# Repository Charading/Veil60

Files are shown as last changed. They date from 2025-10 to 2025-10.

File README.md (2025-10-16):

# The Veil 60% Keyboard
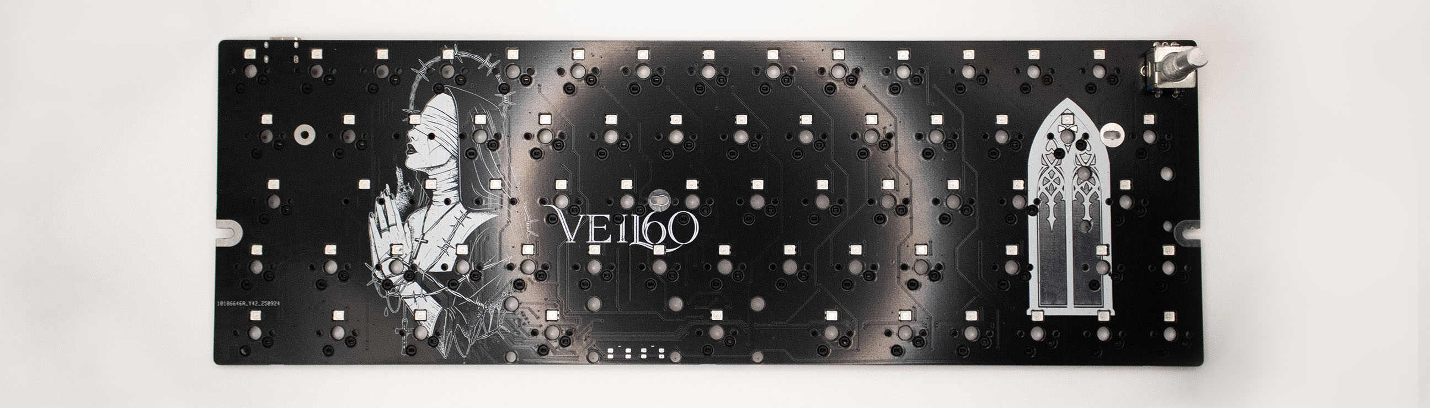
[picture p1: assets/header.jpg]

## Features and Information
- 66 key 60% layout, compatible with 3rd party cases.
- QMK + VIA
- Split space (2.75U + 2.25U + 1.25U)
- WASD are Hall effect sensors with SOCD.
- Custom VIA keycodes for printing ADC values to QMK Toolbox HID Console for calibration
- Fully remappable encoder knob.
- Arrow key cluster
- ISO backslash
- SignalRGB supported
- North-facing RGB
- 12 Underglow LEDS

### [KLE Layout](https://www.keyboard-layout-editor.com/#/gists/70c935bfc0dd9d3efd5b4094877e21a2)
<p align="center">
PCB Front
</p>

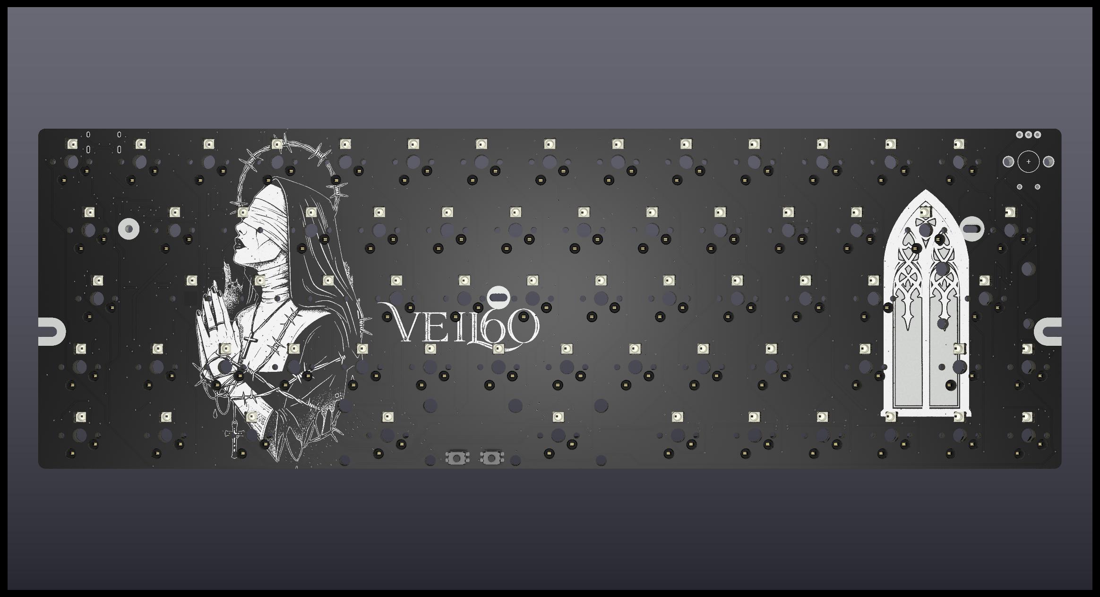
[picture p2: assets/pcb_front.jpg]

<p align="center">
PCB Back
</p>

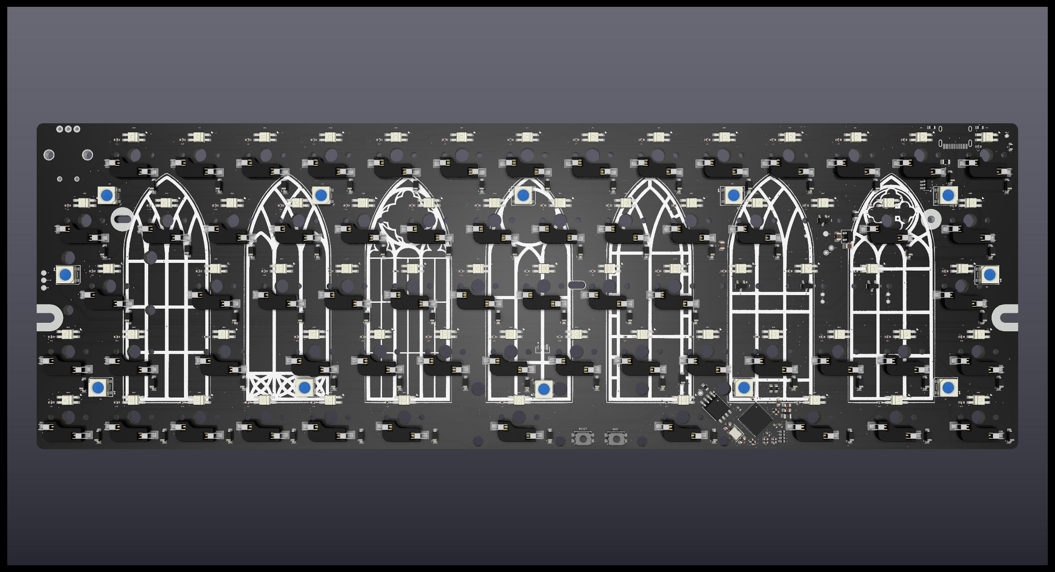
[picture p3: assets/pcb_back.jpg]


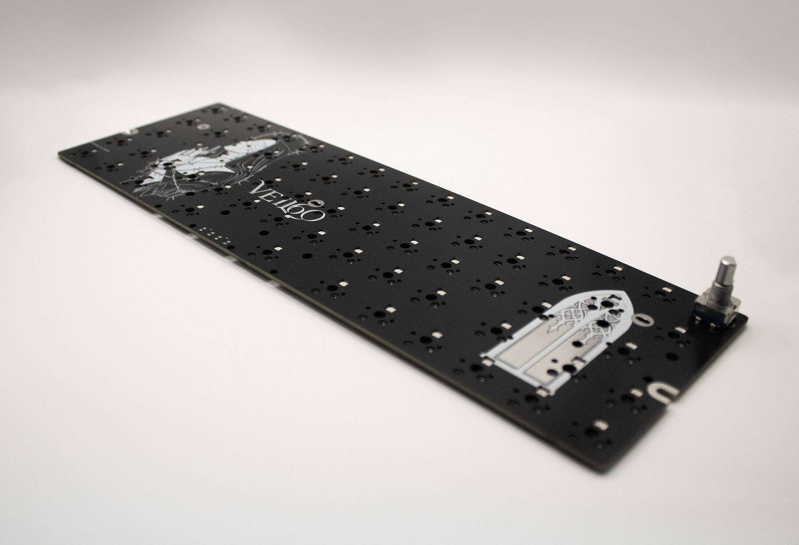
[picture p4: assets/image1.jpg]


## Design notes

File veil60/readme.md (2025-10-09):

# veil60

veil60

*A short description of the keyboard/project*

* Keyboard Maintainer: [Charading](https://github.com/Charading)
* Hardware Supported: *The PCBs, controllers supported*
* Hardware Availability: *Links to where you can find this hardware*

Make example for this keyboard (after setting up your build environment):

    make veil60:default

Flashing example for this keyboard:

    make veil60:default:flash

See the [build environment setup](https://docs.qmk.fm/#/getting_started_build_tools) and the [make instructions](https://docs.qmk.fm/#/getting_started_make_guide) for more information. Brand new to QMK? Start with our [Complete Newbs Guide](https://docs.qmk.fm/#/newbs).

## Bootloader

Enter the bootloader in 3 ways:

* **Bootmagic reset**: Hold down the key at (0,0) in the matrix (usually the top left key or Escape) and plug in the keyboard
* **Physical reset button**: Briefly press the button on the back of the PCB - some may have pads you must short instead
* **Keycode in layout**: Press the key mapped to `QK_BOOT` if it is available

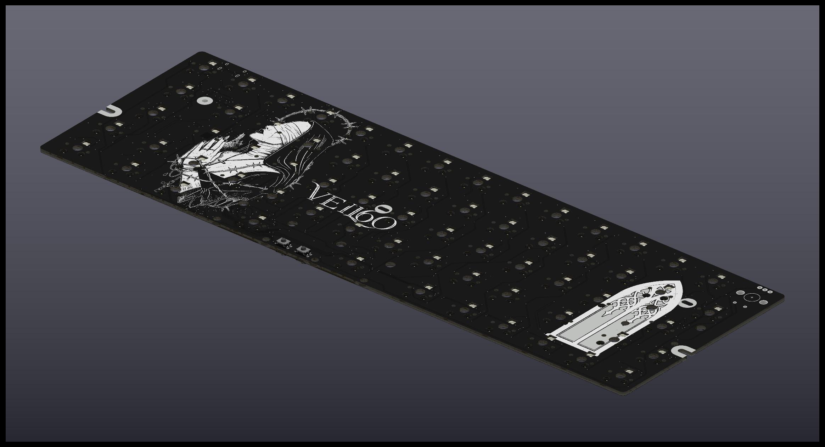
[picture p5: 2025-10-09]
assets/pcb_front_ortho.jpg

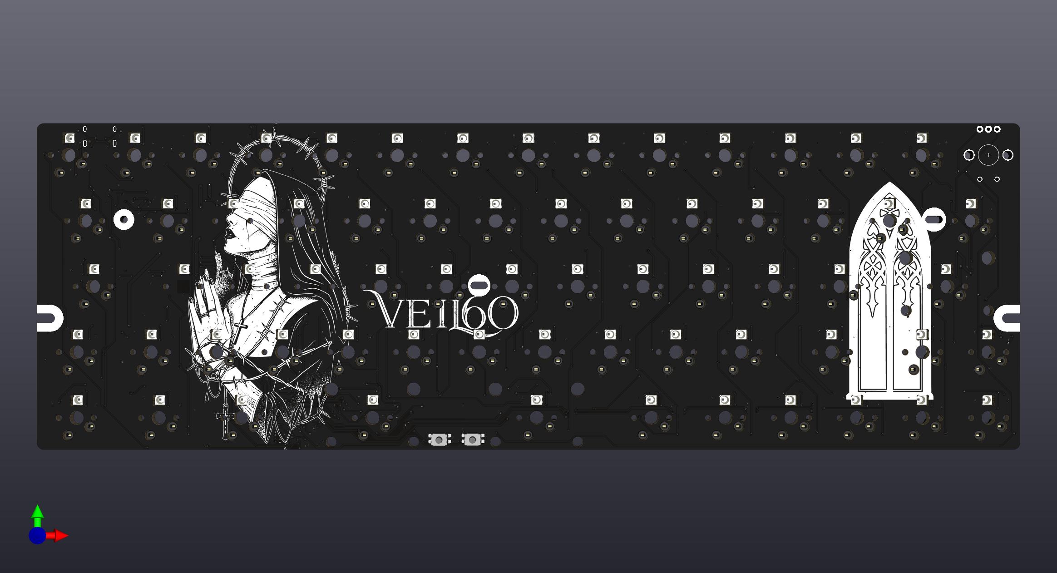
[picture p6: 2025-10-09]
assets/pcb_front_default.jpg

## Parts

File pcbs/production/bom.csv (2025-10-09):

Designator | Footprint | Quantity | Value | LCSC Part #
AC1, AC2, AC3, AC4, C1, C14, C16, C17, C2, C3, C4, C5, C6 | C_0402 | 13 | 0.1uF
BOOT_2, BOOT | SW_SPST_EVQP2_MiddlePushTravel_H2.5mm | 2 | BOOT
C1_2, C2_3, C2_2, C3_2 | TestPoint_Pad_D1.0mm | 4 | 0.1uF
C10 | 0603 | 1 | 0.1uF
C11, C9 | 0603 | 2 | 10uF
C12, C13 | 0603 | 2 | 30p
C15 | C_0402 | 1 | 1u
C18 | 0805 | 1 | 10u
C7, C8 | 0805 | 2 | 4.7uF
D1, D10, D11, D12, D13, D14, D15, D16, D17, D18, D19, D2, D20, D21, D22, D23, D24, D25, D26, D27, D28, D29, D3, D30, D31, D32, D33, D34, D35, D36, D37, D38, D39, D4, D40, D41, D42, D43, D44, D45, D46, D47, D48, D49, D5, D50, D51, D52, D53, D54, D55, D56, D57, D58, D59, D6, D60, D61, D62, D7, D8, D9 | D_SOD-123_Mars | 62 | 1N4148W
ENC1 | RotaryEncoder_MX_EC11_CircularMountingHoles | 1 | RotaryEncoder_Switch_MP
F1 | 0805 | 1 | Polyfuse_Small
FB1 | Ferrite_0805 | 1 | 600R
J1 | USB_C_Receptacle_HRO_TYPE-C-31-M-12 (16P) | 1 | USB_C_Receptacle
L1 | 0805 | 1 | 10uH
LC1, LC10, LC11, LC12, LC13, LC14, LC15, LC16, LC17, LC18, LC19, LC2, LC20, LC21, LC22, LC23, LC24, LC25, LC26, LC27, LC28, LC29, LC3, LC30, LC31, LC32, LC33, LC34, LC35, LC36, LC37, LC38, LC39, LC4, LC40, LC41, LC42, LC43, LC44, LC45, LC46, LC47, LC48, LC49, LC5, LC50, LC51, LC52, LC53, LC54, LC55, LC56, LC57, LC58, LC59, LC6, LC60, LC61, LC62, LC63, LC64, LC65, LC66, LC7, LC8, LC9 | 0402 | 66 | 100n
LED1, LED10, LED11, LED12, LED13, LED14, LED15, LED16, LED17, LED18, LED19, LED2, LED20, LED21, LED22, LED23, LED24, LED25, LED26, LED27, LED28, LED29, LED3, LED30, LED31, LED32, LED33, LED34, LED35, LED36, LED37, LED38, LED39, LED4, LED40, LED41, LED42, LED43, LED44, LED45, LED46, LED47, LED48, LED49, LED5, LED50, LED51, LED52, LED53, LED54, LED55, LED56, LED57, LED58, LED59, LED6, LED60, LED61, LED62, LED63, LED64, LED65, LED66, LED7, LED8, LED9 | LED_6028R | 66 | SK6812MINI-E
MX1 | MX-Hotswap-1U | 1 | Esc
MX10 | MX-Hotswap-1U | 1 | 9
MX11 | MX-Hotswap-1U | 1 | 10
MX12 | MX-Hotswap-1U | 1 | -
MX13 | MX-Hotswap-1U | 1 | =
MX14 | MX-Hotswap-1U | 1 | Back
MX15 | MX-Hotswap-1.5U | 1 | Tab
MX16 | MX-Hotswap-1U | 1 | Q
MX17 | SW_MX_HE_90deg_1u | 1 | W
MX18 | MX-Hotswap-1U | 1 | E
MX19 | MX-Hotswap-1U | 1 | R
MX2 | MX-Hotswap-1U | 1 | 1
MX20 | MX-Hotswap-1U | 1 | T
MX21 | MX-Hotswap-1U | 1 | Y
MX22 | MX-Hotswap-1U | 1 | U
MX23 | MX-Hotswap-1U | 1 | I
MX24 | MX-Hotswap-1U | 1 | O
MX25 | MX-Hotswap-1U | 1 | P
MX26 | MX-Hotswap-1U | 1 | [
MX27 | MX-Hotswap-1U | 1 | ]
MX28 | MX-Hotswap-1.5U | 1 | #
MX29 | MX-Hotswap-1.75U | 1 | Caps
MX3 | MX-Hotswap-1U | 1 | 2
MX30 | SW_MX_HE_90deg_1u | 1 | A
MX31 | SW_MX_HE_90deg_1u | 1 | S
MX32 | SW_MX_HE_90deg_1u | 1 | D
MX33 | MX-Hotswap-1U | 1 | F
MX34 | MX-Hotswap-1U | 1 | G
MX35 | MX-Hotswap-1U | 1 | H
MX36 | MX-Hotswap-1U | 1 | J
MX37 | MX-Hotswap-1U | 1 | K
MX38 | MX-Hotswap-1U | 1 | L
MX39 | MX-Hotswap-1U | 1 | ;:
MX4 | MX-Hotswap-1U | 1 | 3
MX40 | MX-Hotswap-1U | 1 | '@
MX41 | MX-Hotswap-2.25U | 1 | Enter
MX42 | MX-Hotswap-1.25U | 1 | L_Shift
MX43 | MX-Hotswap-1U | 1 | \
MX44 | MX-Hotswap-1U | 1 | Z
MX45 | MX-Hotswap-1U | 1 | X
MX46 | MX-Hotswap-1U | 1 | C
MX47 | MX-Hotswap-1U | 1 | V
MX48 | MX-Hotswap-1U | 1 | B
MX49 | MX-Hotswap-1U | 1 | N
MX5 | MX-Hotswap-1U | 1 | 4
MX50 | MX-Hotswap-1U | 1 | M
MX51 | MX-Hotswap-1U | 1 | ,<
MX52 | MX-Hotswap-1U | 1 | .>
MX53 | MX-Hotswap-1.75U | 1 | R_Shift
MX54 | MX-Hotswap-1U | 1 | Up
MX55 | MX-Hotswap-1U | 1 | /?
MX56 | MX-Hotswap-1.25U | 1 | L_Ctrl
MX57 | MX-Hotswap-1.25U | 1 | Win
MX58 | MX-Hotswap-1.25U | 1 | L_Alt
MX59 | MX-Hotswap-2.75U | 1 | Space1
MX6 | MX-Hotswap-1U | 1 | 5
MX60 | MX-Hotswap-2.25U | 1 | Space2
MX61 | MX-Hotswap-1.25U | 1 | Space3
MX62 | MX-Hotswap-1U | 1 | R_Alt
MX63 | MX-Hotswap-1U | 1 | Fn
MX64 | MX-Hotswap-1U | 1 | Left
MX65 | MX-Hotswap-1U | 1 | Down
MX66 | MX-Hotswap-1U | 1 | Right
MX7 | MX-Hotswap-1U | 1 | 6
MX8 | MX-Hotswap-1U | 1 | 7
MX9 | MX-Hotswap-1U | 1 | 8
R1_2, R2_4, R2_3, R2_2 | TestPoint_Pad_D1.0mm | 4 | 5.1k
R1, R2 | R_0603 | 2 | 5.1k
R10, R7, R8, R9 | R_0402 | 4 | 1k
R3 | R_0603 | 1 | 10K
R4, R5 | R_0603 | 2 | 27R
R6 | R_0603 | 1 | 330
RESET_2, RESET | SW_SPST_EVQP2_MiddlePushTravel_H2.5mm | 2 | RESET
U1 | SOT-23-5 | 1 | AP2112K-3.3TRG1
U2 | SOT-23-6 | 1 | USBLC6-2SC6
U3 | SOIC-8_5.3x5.3mm_P1.27mm | 1 | W25Q128JVS
U4 | QFN-56-1EP_7x7mm_P0.4mm_EP3.2x3.2mm | 1 | RP2040
UG1 | LED_WS2812B-4020 | 1 | WS2812_4020
UL1, UL10, UL11, UL12, UL2, UL3, UL4, UL5, UL6, UL7, UL8, UL9 | LED_WS2812B_PLCC4_5.0x5.0mm_P3.2mm | 12 | WS2812B
Y1 | Crystal_SMD_3225-4Pin_3.2x2.5mm | 1 | 12MHz

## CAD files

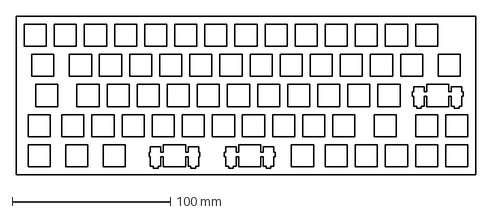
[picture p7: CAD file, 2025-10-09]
veil60/veil60_plate.dxf
290.7 x 100.2 mm

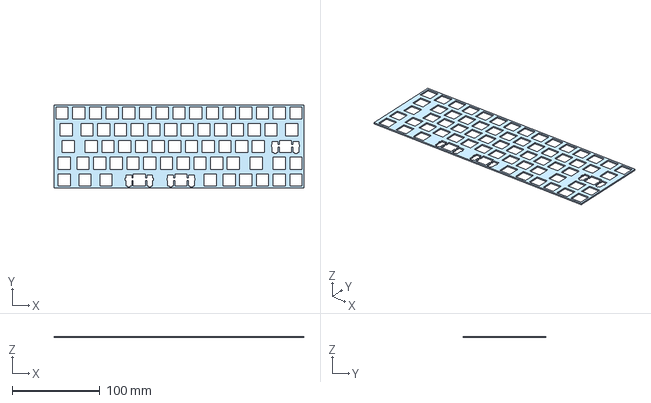
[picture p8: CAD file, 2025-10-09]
veil60_plate.step
285.0 x 94.6 x 1.50 mm

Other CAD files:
veil60_plate_split.step

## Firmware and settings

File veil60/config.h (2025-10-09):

#pragma once

// Console for debugging (enabled via keyboard.json)


#define ENCODER_BUTTON_PIN GP14


// ADC configuration for DRV5055A4 hall effect sensors
#define ADC_BUFFER_DEPTH 4
#define ADC_SAMPLING_RATE 10000


// SOCD configuration
#define SOCD_TIMEOUT 50 // ms timeout for SOCD cleaning

// Custom matrix scanning interval
#define MATRIX_SCAN_RATE 1000 // 1kHz scan rate for hall effect sensors

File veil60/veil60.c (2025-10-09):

#include "veil60.h"
#include "socd.h"
#include "analog.h"
#include "timer.h"
#include "print.h"
#include "config.h"

// Hall sensor states
static hall_sensor_t hall_sensors[4] = {0};
static uint32_t last_adc_print = 0;

// Hall effect sensor threshold (single threshold, no hysteresis)
// DRV5055A4: typical mid-scale ~2048 for 12-bit; values here are raw ADC units
// Actuation when ADC > HALL_THRESHOLD, release when ADC <= HALL_THRESHOLD
#define HALL_THRESHOLD 545

#include "bootloader.h"
// Note: BOOT keycode is defined in the keymap as BOOT_KEY (SAFE_RANGE). Do not redefine here.
// Bootloader helper is available via bootloader.h
// ...existing code...


// Hall sensor scanning (runs alongside normal matrix)
void hall_sensor_scan(void) {
    // Scan every cycle for gaming (no delay)
    hall_sensors_task();
    
    // Print ADC values every 100ms for calibration
    if (timer_elapsed32(last_adc_print) > 100) {
        print_adc_values();
        last_adc_print = timer_read32();
    }
}

void hall_sensors_init(void) {
    // Initialize ADC pins
    analogReadPin(KEY_W);
    analogReadPin(KEY_A);
    analogReadPin(KEY_S);
    analogReadPin(KEY_D);
    
    // Initialize SOCD
    socd_init();
    // Init encoder switch if defined
#ifdef ENCODER_BUTTON_PIN
    setPinInputHigh(ENCODER_BUTTON_PIN); // enable pull-up
#endif
    // Initialize debounce state for hall sensors
    for (int i = 0; i < 4; ++i) {
        hall_sensors[i].last_debounce = timer_read32();
        hall_sensors[i].raw_pressed = false;
        hall_sensors[i].previous_state = false;
        hall_sensors[i].sent_state = false;
        hall_sensors[i].desired_state = false;
        hall_sensors[i].raw_value = 0;
    }
}

void hall_sensors_task(void) {
    // Read all hall sensors
    read_hall_sensor(ADC_W_CHANNEL, &hall_sensors[0]);
    read_hall_sensor(ADC_A_CHANNEL, &hall_sensors[1]);
    read_hall_sensor(ADC_S_CHANNEL, &hall_sensors[2]);
    read_hall_sensor(ADC_D_CHANNEL, &hall_sensors[3]);
    
    // Process key states with SOCD and direct keycode injection
    for (uint8_t i = 0; i < 4; ++i) {
        if (hall_sensors[i].is_pressed != hall_sensors[i].previous_state) {
            // Map sensor index to keycode
            uint16_t kc = KC_NO;
            switch (i) {
                case 0: kc = KC_W; break;
                case 1: kc = KC_A; break;
                case 2: kc = KC_S; break;
                case 3: kc = KC_D; break;
            }
            
            // Process through SOCD system with is_hall=true
            // This will automatically handle register_code/unregister_code calls
            socd_process_key(kc, hall_sensors[i].is_pressed, true);
            
            hall_sensors[i].sent_state = hall_sensors[i].is_pressed;
            hall_sensors[i].previous_state = hall_sensors[i].is_pressed;
        }
    }
}

bool read_hall_sensor(uint8_t channel, hall_sensor_t* sensor) {
    uint16_t adc_value;
    
    switch (channel) {
        case ADC_W_CHANNEL:
            adc_value = analogReadPin(KEY_W);
            break;
        case ADC_A_CHANNEL:
            adc_value = analogReadPin(KEY_A);
            break;
        case ADC_S_CHANNEL:
            adc_value = analogReadPin(KEY_S);
            break;
        case ADC_D_CHANNEL:
            adc_value = analogReadPin(KEY_D);
            break;
        default:
            return false;
    }
    
    sensor->raw_value = adc_value;
    // Simple debounce: detect raw pressed state and require it to be stable for 30ms
    bool currently_raw = (adc_value > HALL_THRESHOLD);
    if (currently_raw != sensor->raw_pressed) {
        // state changed, reset debounce timer
        sensor->last_debounce = timer_read32();
        sensor->raw_pressed = currently_raw;
    }
    // Only commit to is_pressed if stable for 30ms
    if (timer_elapsed32(sensor->last_debounce) >= 30) {
        sensor->is_pressed = sensor->raw_pressed;
    }
    
    return true;
}

void print_adc_values(void) {
    // Only print if enabled by keymap (ADC debug prints are allowed)
    if (adc_printing_enabled) {
        uprintf("ADC: W=%d A=%d S=%d D=%d | Pressed: W=%d A=%d S=%d D=%d\n",
                hall_sensors[0].raw_value,
                hall_sensors[1].raw_value,
                hall_sensors[2].raw_value,
                hall_sensors[3].raw_value,
                hall_sensors[0].is_pressed,
                hall_sensors[1].is_pressed,
                hall_sensors[2].is_pressed,
                hall_sensors[3].is_pressed);
    }
}

// QMK callback: Initialize keyboard
void keyboard_pre_init_kb(void) {
    hall_sensors_init();
    keyboard_pre_init_user();
}

// QMK callback: Called every matrix scan cycle
void matrix_scan_kb(void) {
    // Scan hall effect sensors (runs on top of normal matrix)
    hall_sensor_scan();
    
    // Run SOCD task
    socd_task();
    
    // Hall sensors now use direct keycode injection instead of matrix injection
    // No need to manipulate matrix[] directly or process physical inputs
    
    // Call user's matrix_scan callback
    matrix_scan_user();
}

// Trigger RP2040 bootloader safely from code or keymap
void veil60_bootloader(void) {
#if defined(RESET_USB_BOOT) || defined(usb_boot)
    // Prefer QMK helper if available
    reset_usb_boot(0, 0);
#elif defined(bootloader_jump)
    bootloader_jump();
#else
    // Fallback: use generic reset (may not enter UF2)
    reset_keyboard();
#endif
}

// (moved earlier)

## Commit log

2025-10-09 Added plates and reorganised file structure.
    [veil60_plate.step, veil60_plate_split.step]
2025-10-16 Update PCB image labels in README.md
